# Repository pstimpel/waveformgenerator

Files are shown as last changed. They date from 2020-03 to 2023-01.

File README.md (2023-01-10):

# Waveform Generator

Video on Youtube (https://www.youtube.com/watch?v=MJ1rr9S12Lc)

Click to play video

First of all, the credit for creating the basic circuit goes to Scullcom Hobby Electronics Youtube channel, who is inactive meanwhile - sadly.

https://www.youtube.com/channel/UCDqryeq1kMDSEQwltWqASrA

Project page at Thingiverse: https://www.thingiverse.com/thing:4243526

Project page at Prusaprinters: https://www.prusaprinters.org/prints/27172-xr2206-waveform-generator

## Why?

Someone said: when starting the hobby electronics, you will need to build 2 things, a power supply and a waveform generator.

## Again, why?

I was keen to dive into electronics again, after 20 years of ignoring this hobby. To get some practice again, I thought building such a generator would be fun. It was fun. 

## What did you change on the original circuit?

Based on Scullcoms circuit I started creating an Arduino controlled waveform gegenerator. My goal was to control as much as possible by the Arduino. So I removed the following parts from the original circuit:

* switch for changing from sine to triangle wave
* switch for changing from sine/triangle to square wave
* switch for enabling pulse width modulation
* switch for changing the frequency range

I replaced them with a relay and some opto isolators.

## Was there any challenge?

Uh, plenty of challenges. 

Figuring out how to replace mechanical switches by opto isolators and relay was kind of a long way for me. First of, I tried to do it by simple transistors, and failed. So opto isolators were the next try, and I was able to replace 3 of 4 switches by these ICs. One left. So I tried a micro relay, and this worked out great.

Another issue I had was to balance out the whole circuit, so I would be able to select halfway decent frequency ranges. Finally, a big enough coarse frequency potentiometer combined with a trim poti did the trick. My goal was to have kind of smooth waveforms, not to hunt Megahertzes for the marketing paper. 

I built the whole circuit at least 4 times on breadboards. And what to tell: those breadboards can be a pain in the ass, at least the cheapos. 

## What can you expect?

You will get a waveform generator able to generate sine, triangle and square waves. The frequency range is from about 1 Hz up to 100 kHz, split into 5 ranges you can switch between (1-10, 10-100, 100 to 1,000, 1,000 to 10,000 and 10,000 to 100,000 Hz, roughly). You can adjust the frequency within these ranges by two potis. The amplitude is about +5 to -5 V (adjustable) at the 50 Ohms output, and from 0 to 5V at the TTL output. There is a basic Pulse width modulation available as well. You can adjust the pulse width. By combining sine or triangle waves and PWM you recieve kind of a ramp modulation. The waveform is quite solid, but with 100kHz you will see some distortion and spikes. It seems this is kind of a typical behavior of the XR2206 chipset. There is a frequency counter used to display the set frequency. However, this is kind of an estimation, especially in very low Hz ranges.

## What you will find in this repository

### Folder enclosure

This folder contains the stl files to 3D print the enclosure. I was using PLA and my Prusa I3 Mk3 printer. On top, there are 2 PDFs containing labels. You could just print them, cut them out of the sheet of paper, use an exacto knife to cut the holes, and mount it to the front of your enclosure

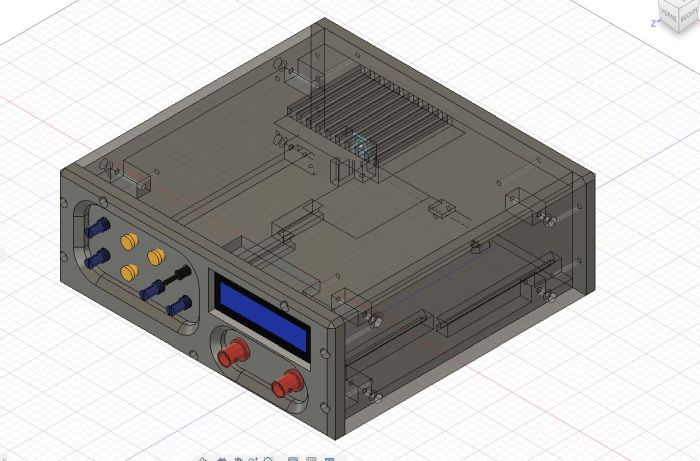
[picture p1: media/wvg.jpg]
Enclosure in Fusion 360


### Folder circuits

There are 2 circuits. One keeps all the control stuff and the Arduino, and the other creates the waveform and gets controlled by the control board. There are gerber files, the KICAD board file, and PDFs with the circuit scheme itself. In each subfolder you wil find a list of parts. 

## What to buy (BOM)

Beside the stuff from the parts lists in the circuit folders, you will need

* potentiometer 10k linear, 6mm axle (gain control)
* potentiometer 1M linear, 6mm axle (frequency control, coarse)
* potentiometer 10k linear, 6mm axle (frequency control, fine)
* potentiometer 1ook linear, 6mm axle (PWM control)
* 3 push buttons, closing type, like in https://www.amazon.de/gp/product/B07MY2WVQ3
* 1 switch, like in https://www.amazon.de/gp/product/B07MY2WVQ3
* 1 smaller heatsink for TO220, LM7812
* 1 midsze heatsink for TO220, LM7805
* 15 V power supply with 5.5x2.1 connector
* matching 5.5x2.1 socket for your power supply
* 25 cylinderhead screws, M3x12
* 16x2 I2C LED for Arduino
* 2 BNC sockets
* wires
* Pinheaders 2.54mm
* matching IC sockets if you dislike soldering the ICs to the PCB directly (2x 8pin, 1x 14pin, 3x 16pin)
* 3 screw terminals, 2 poles, 5mm 
* dupont style wires or similar to connect to pinheaders

## Howto

### Fast lane

Order PCBs and parts, solder all the stuff together, patch the Arduino using the sketch provided, 3d Print the enclosure, put PCBs inside enclosure, mount LCD, potis and switches to the front, solder dupont style wires to them, connect with the PCBs, mount BNC sockets to the front, use some cable to connect them to the PCB, insert 5.5x2.1 soocket in its pocket, lock it using the lock, connect it to the PCB. Lock the PCBs using the pcblock, secure it using one of the screws. Close the enclosure. Connect power, switch the device on, and have fun.

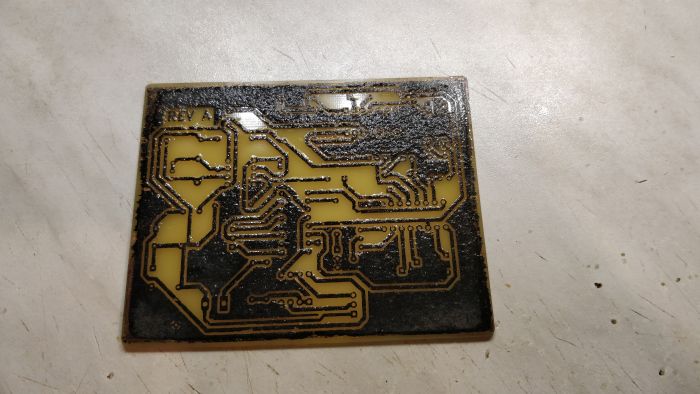
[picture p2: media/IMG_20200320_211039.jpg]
Etching one of the PCBs


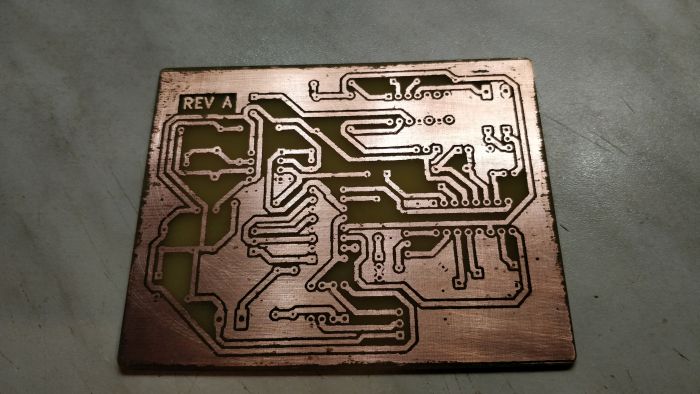
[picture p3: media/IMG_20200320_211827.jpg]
Final PCB


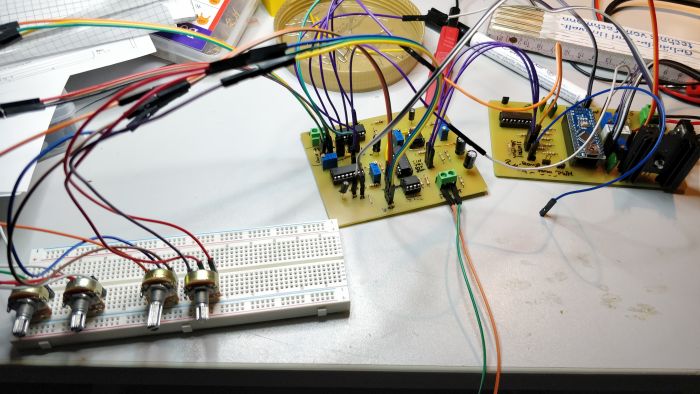
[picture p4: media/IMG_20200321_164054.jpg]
Does it work?


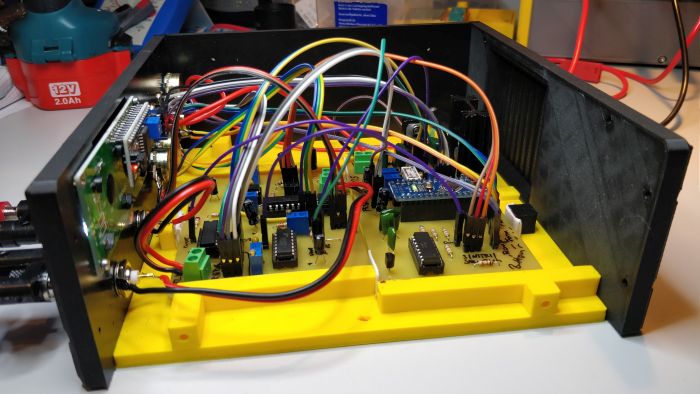
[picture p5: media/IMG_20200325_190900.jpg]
Put the stuff into the enclosure


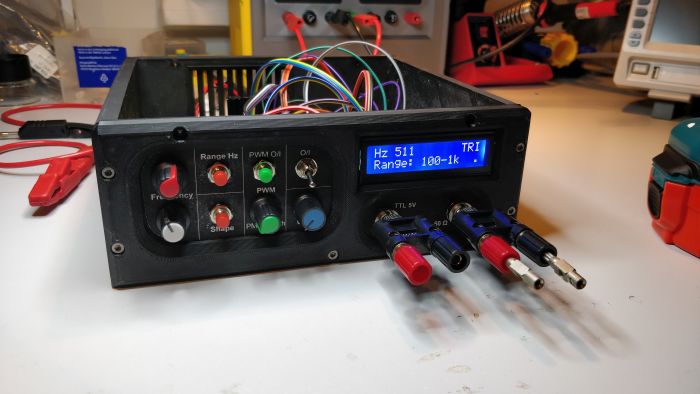
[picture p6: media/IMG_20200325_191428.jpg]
Still working?


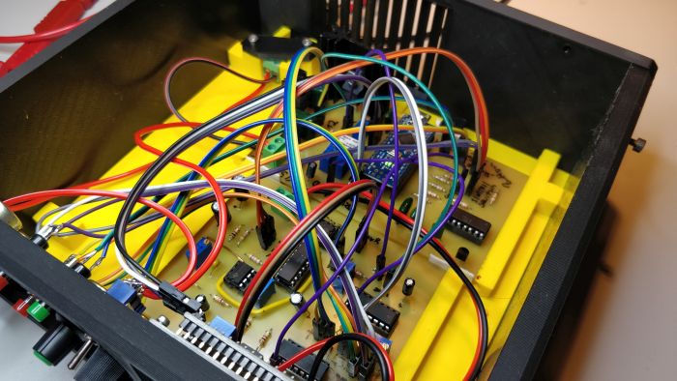
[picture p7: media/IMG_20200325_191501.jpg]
Some mayhem


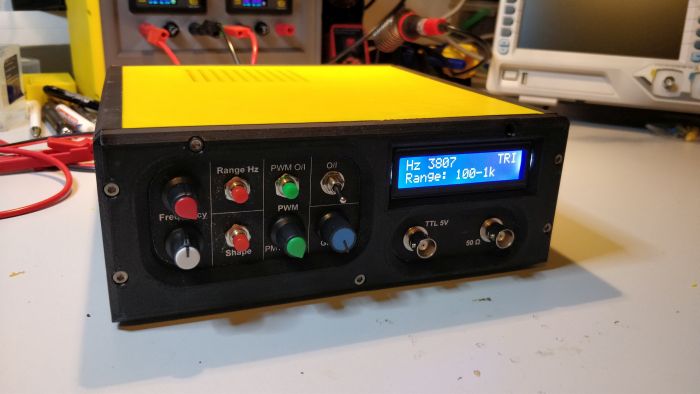
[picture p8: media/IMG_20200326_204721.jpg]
Done!


## Remarks, hints

### Arduino

To run the display you will need to add library LiquidCrystal_I2C by Frank de Brabander.

To have frequence counting, you will need to add library FreqCounter by Martin Nawrath.

### Breadboarding

I highly recommend testing the circuit on a breadboard before you go for the soldering stuff. You will learn much more that way than by just following this rough guide. 

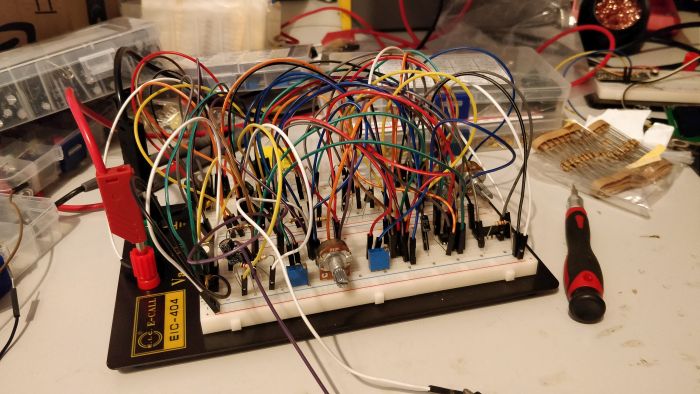
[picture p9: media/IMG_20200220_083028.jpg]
Half of the circuit


### Pricing vs functionality vs fun

If you look for a decent waveform generator delivering Megahertz samples, buy one. 

If you look for the cheapest of all solutions, by such a chinese XR2206 kit for less than 10 USD.

If you want to enjoy DIY, start buying parts and follow the guide I provided. Good luck, wish you well.

### Credits

'rine 77' https://github.com/rine77 contributed updated circuit data, compatible with Kicad6

## CORONA

This project was finished during the spare time provided by Corona. If someone reads this in the future, I really hope Corona is no issue anymore. Until then: stay safe, wash your hands, and take care of your family.

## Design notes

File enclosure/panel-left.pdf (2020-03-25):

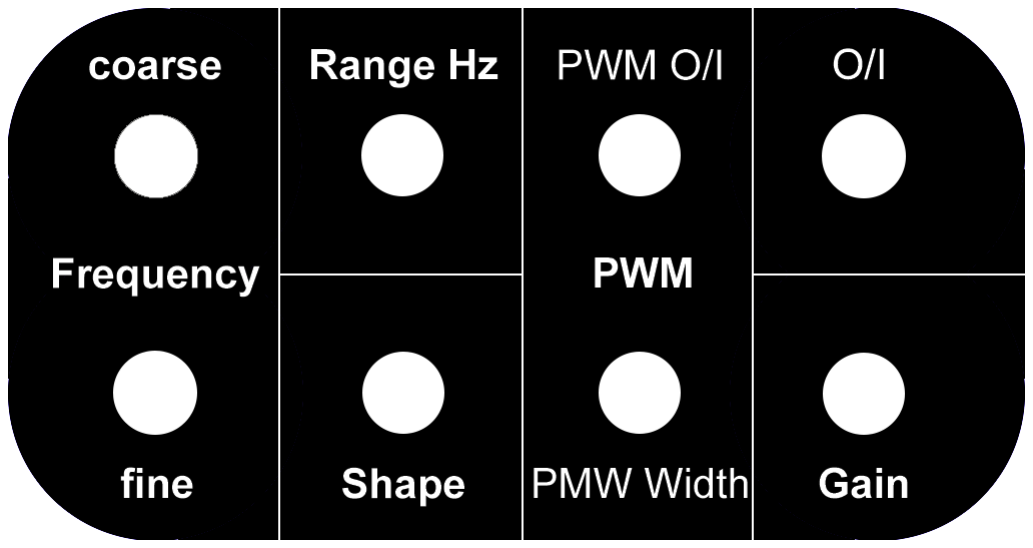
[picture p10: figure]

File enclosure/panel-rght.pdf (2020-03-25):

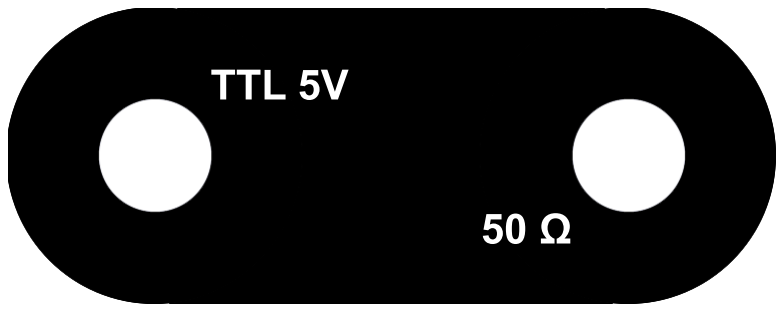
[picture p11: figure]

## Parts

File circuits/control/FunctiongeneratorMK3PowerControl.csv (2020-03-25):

Ref | Value | Part | Footprint | Description | Vendor
A1 | Arduino_Nano_v3.x | MCU_Module:Arduino_Nano_v3.x | Module:Arduino_Nano | Arduino Nano v3.x
C1 | 100nF | Device:C | Capacitor_THT:C_Disc_D8.0mm_W5.0mm_P7.50mm | Unpolarized capacitor
C2 | 1uF | Device:CP | Capacitor_THT:CP_Radial_D8.0mm_P5.00mm | Polarized capacitor
C3 | 330nF | Device:C | Capacitor_THT:C_Disc_D8.0mm_W5.0mm_P7.50mm | Unpolarized capacitor
C4 | 330nF | Device:C | Capacitor_THT:C_Disc_D8.0mm_W5.0mm_P7.50mm | Unpolarized capacitor
C5 | 100nF | Device:C | Capacitor_THT:C_Disc_D8.0mm_W5.0mm_P7.50mm | Unpolarized capacitor
C6 | 100nF | Device:C | Capacitor_THT:C_Disc_D8.0mm_W5.0mm_P7.50mm | Unpolarized capacitor
C7 | 10uF | Device:CP | Capacitor_THT:CP_Radial_D8.0mm_P5.00mm | Polarized capacitor
C8 | 1nF | Device:C | Capacitor_THT:C_Disc_D8.0mm_W5.0mm_P7.50mm | Unpolarized capacitor
C9 | 10nF | Device:C | Capacitor_THT:C_Disc_D8.0mm_W5.0mm_P7.50mm | Unpolarized capacitor
D1 | 1N4007 | Diode:1N4007 | Diode_THT:D_DO-41_SOD81_P10.16mm_Horizontal | 1000V 1A General Purpose Rectifier Diode, DO-41
D2 | 1N4007 | Diode:1N4007 | Diode_THT:D_DO-41_SOD81_P10.16mm_Horizontal | 1000V 1A General Purpose Rectifier Diode, DO-41
J1 | SIN-TRI-SQU-PWM | Connector:Conn_01x03_Male | Connector_PinHeader_2.54mm:PinHeader_1x03_P2.54mm_Vertical | Generic connector, single row, 01x03, script generated (kicad-library-utils/schlib/autogen/connector/)
J2 | BTN Range | Connector:Conn_01x02_Male | Connector_PinHeader_2.54mm:PinHeader_1x02_P2.54mm_Vertical | Generic connector, single row, 01x02, script generated (kicad-library-utils/schlib/autogen/connector/)
J3 | BTN Form | Connector:Conn_01x02_Male | Connector_PinHeader_2.54mm:PinHeader_1x02_P2.54mm_Vertical | Generic connector, single row, 01x02, script generated (kicad-library-utils/schlib/autogen/connector/)
J4 | BTN PWM | Connector:Conn_01x02_Male | Connector_PinHeader_2.54mm:PinHeader_1x02_P2.54mm_Vertical | Generic connector, single row, 01x02, script generated (kicad-library-utils/schlib/autogen/connector/)
J5 | FreqRange | Connector:Conn_01x02_Male | Connector_PinHeader_2.54mm:PinHeader_1x02_P2.54mm_Vertical | Generic connector, single row, 01x02, script generated (kicad-library-utils/schlib/autogen/connector/)
J6 | WaveA1 | Connector:Conn_01x01_Male | Connector_PinHeader_2.54mm:PinHeader_1x01_P2.54mm_Vertical | Generic connector, single row, 01x01, script generated (kicad-library-utils/schlib/autogen/connector/)
J7 | FreqCount | Connector:Conn_01x01_Male | Connector_PinHeader_2.54mm:PinHeader_1x01_P2.54mm_Vertical | Generic connector, single row, 01x01, script generated (kicad-library-utils/schlib/autogen/connector/)
J8 | Display | Connector:Conn_01x04_Male | Connector_PinHeader_2.54mm:PinHeader_1x04_P2.54mm_Vertical | Generic connector, single row, 01x04, script generated (kicad-library-utils/schlib/autogen/connector/)
J9 | 14V | Connector:Screw_Terminal_01x02 | TerminalBlock:TerminalBlock_Altech_AK300-2_P5.00mm | Generic screw terminal, single row, 01x02, script generated (kicad-library-utils/schlib/autogen/connector/)
J10 | 12V GND 5V | Connector:Conn_01x03_Male | Connector_PinHeader_2.54mm:PinHeader_1x03_P2.54mm_Vertical | Generic connector, single row, 01x03, script generated (kicad-library-utils/schlib/autogen/connector/)
J11 | WaveA2 | Connector:Conn_01x01_Male | Connector_PinHeader_2.54mm:PinHeader_1x01_P2.54mm_Vertical | Generic connector, single row, 01x01, script generated (kicad-library-utils/schlib/autogen/connector/)
J12 | MO | Connector:Conn_01x01_Male | Connector_PinHeader_2.54mm:PinHeader_1x01_P2.54mm_Vertical | Generic connector, single row, 01x01, script generated (kicad-library-utils/schlib/autogen/connector/)
K1 | G6S-2 | Relay:G6S-2 | Relay_THT:Relay_DPDT_Omron_G6S-2 | Compact, Industry-Standard 2-pole relay, designed to switch 2A Signal Loads, Single-side Stable
Q1 | BC337 | Transistor_BJT:BC337 | Package_TO_SOT_THT:TO-220-3_Vertical | 0.8A Ic, 45V Vce, NPN Transistor, TO-92
R1 | 390R | Device:R | Resistor_THT:R_Axial_DIN0207_L6.3mm_D2.5mm_P10.16mm_Horizontal | Resistor
R2 | 390R | Device:R | Resistor_THT:R_Axial_DIN0207_L6.3mm_D2.5mm_P10.16mm_Horizontal | Resistor
R3 | 390 | Device:R | Resistor_THT:R_Axial_DIN0207_L6.3mm_D2.5mm_P10.16mm_Horizontal | Resistor
R4 | 270 | Device:R | Resistor_THT:R_Axial_DIN0207_L6.3mm_D2.5mm_P10.16mm_Horizontal | Resistor
R5 | 390 | Device:R | Resistor_THT:R_Axial_DIN0207_L6.3mm_D2.5mm_P10.16mm_Horizontal | Resistor
R6 | 10k | Device:R | Resistor_THT:R_Axial_DIN0207_L6.3mm_D2.5mm_P10.16mm_Horizontal | Resistor
R7 | 10k | Device:R | Resistor_THT:R_Axial_DIN0207_L6.3mm_D2.5mm_P10.16mm_Horizontal | Resistor
R8 | 10k | Device:R | Resistor_THT:R_Axial_DIN0207_L6.3mm_D2.5mm_P10.16mm_Horizontal | Resistor
R9 | 390R | Device:R | Resistor_THT:R_Axial_DIN0207_L6.3mm_D2.5mm_P10.16mm_Horizontal | Resistor
R10 | 390R | Device:R | Resistor_THT:R_Axial_DIN0207_L6.3mm_D2.5mm_P10.16mm_Horizontal | Resistor
RV1 | 500 | Device:R_POT_TRIM | Potentiometer_THT:Potentiometer_Bourns_3266Y_Vertical | Trim-potentiometer
RV2 | 50k | Device:R_POT_TRIM | Potentiometer_THT:Potentiometer_Bourns_3266Y_Vertical | Trim-potentiometer
RV3 | 50k | Device:R_POT_TRIM | Potentiometer_THT:Potentiometer_Bourns_3266Y_Vertical | Trim-potentiometer
U1 | LTV-847 | Isolator:LTV-847 | Package_DIP:DIP-16_W7.62mm | Quad DC Optocoupler, Vce 35V, CTR 50%, DIP-16
U2 | LM7812_TO220 | Regulator_Linear:LM7812_TO220 | Package_TO_SOT_THT:TO-220-3_Vertical | Positive 1A 35V Linear Regulator, Fixed Output 12V, TO-220
U3 | LM7805_TO220 | Regulator_Linear:LM7805_TO220 | Package_TO_SOT_THT:TO-220-3_Vertical | Positive 1A 35V Linear Regulator, Fixed Output 5V, TO-220

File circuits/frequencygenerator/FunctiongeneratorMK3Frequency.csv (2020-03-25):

Ref | Value | Part | Footprint | Description | Vendor
C1 | 100pF | Device:C | Capacitor_THT:C_Disc_D9.0mm_W5.0mm_P7.50mm | Unpolarized capacitor
C2 | 10uF | Device:CP | Capacitor_THT:CP_Radial_D8.0mm_P5.00mm | Polarized capacitor
C3 | 10u | Device:CP | Capacitor_THT:CP_Radial_D8.0mm_P5.00mm | Polarized capacitor
C4 | 1u | Device:CP | Capacitor_THT:CP_Radial_D8.0mm_P5.00mm | Polarized capacitor
C6 | 220uF | Device:CP | Capacitor_THT:CP_Radial_D8.0mm_P5.00mm | Polarized capacitor
C7 | 220uF | Device:CP | Capacitor_THT:CP_Radial_D8.0mm_P5.00mm | Polarized capacitor
C8 | 100pF | Device:C | Capacitor_THT:C_Disc_D9.0mm_W5.0mm_P7.50mm | Unpolarized capacitor
J1 | FreqRange | Connector:Conn_01x02_Male | Connector_PinHeader_2.54mm:PinHeader_1x02_P2.54mm_Vertical | Generic connector, single row, 01x02, script generated (kicad-library-utils/schlib/autogen/connector/)
J2 | WaveA1 | Connector:Conn_01x01_Male | Connector_PinHeader_2.54mm:PinHeader_1x01_P2.54mm_Vertical | Generic connector, single row, 01x01, script generated (kicad-library-utils/schlib/autogen/connector/)
J3 | 12V-GND-5V | Connector:Conn_01x03_Male | Connector_PinHeader_2.54mm:PinHeader_1x03_P2.54mm_Vertical | Generic connector, single row, 01x03, script generated (kicad-library-utils/schlib/autogen/connector/)
J4 | FreqCounterD5 | Connector:Conn_01x01_Male | Connector_PinHeader_2.54mm:PinHeader_1x01_P2.54mm_Vertical | Generic connector, single row, 01x01, script generated (kicad-library-utils/schlib/autogen/connector/)
J5 | TTL OUT | Connector:Screw_Terminal_01x02 | TerminalBlock:TerminalBlock_Altech_AK300-2_P5.00mm | Generic screw terminal, single row, 01x02, script generated (kicad-library-utils/schlib/autogen/connector/)
J6 | SIN-TRI-SQU-PWM | Connector:Conn_01x03_Male | Connector_PinHeader_2.54mm:PinHeader_1x03_P2.54mm_Vertical | Generic connector, single row, 01x03, script generated (kicad-library-utils/schlib/autogen/connector/)
J7 | PulseWidth 100k | Connector:Conn_01x03_Male | Connector_PinHeader_2.54mm:PinHeader_1x03_P2.54mm_Vertical | Generic connector, single row, 01x03, script generated (kicad-library-utils/schlib/autogen/connector/)
J8 | FreqCoarse 1M | Connector:Conn_01x03_Male | Connector_PinHeader_2.54mm:PinHeader_1x03_P2.54mm_Vertical | Generic connector, single row, 01x03, script generated (kicad-library-utils/schlib/autogen/connector/)
J9 | FreqFine 10k | Connector:Conn_01x03_Male | Connector_PinHeader_2.54mm:PinHeader_1x03_P2.54mm_Vertical | Generic connector, single row, 01x03, script generated (kicad-library-utils/schlib/autogen/connector/)
J10 | 50 Ohm OUT | Connector:Screw_Terminal_01x02 | TerminalBlock:TerminalBlock_Altech_AK300-2_P5.00mm | Generic screw terminal, single row, 01x02, script generated (kicad-library-utils/schlib/autogen/connector/)
J11 | OUT Gain 10k | Connector:Conn_01x03_Male | Connector_PinHeader_2.54mm:PinHeader_1x03_P2.54mm_Vertical | Generic connector, single row, 01x03, script generated (kicad-library-utils/schlib/autogen/connector/)
J12 | WaveA2 | Connector:Conn_01x01_Male | Connector_PinHeader_2.54mm:PinHeader_1x01_P2.54mm_Vertical | Generic connector, single row, 01x01, script generated (kicad-library-utils/schlib/autogen/connector/)
J13 | MO | Connector:Conn_01x01_Male | Connector_PinHeader_2.54mm:PinHeader_1x01_P2.54mm_Vertical | Generic connector, single row, 01x01, script generated (kicad-library-utils/schlib/autogen/connector/)
R2 | 1k | Device:R | Resistor_THT:R_Axial_DIN0207_L6.3mm_D2.5mm_P10.16mm_Horizontal | Resistor
R5 | 1k | Device:R | Resistor_THT:R_Axial_DIN0207_L6.3mm_D2.5mm_P10.16mm_Horizontal | Resistor
R6 | 1k | Device:R | Resistor_THT:R_Axial_DIN0207_L6.3mm_D2.5mm_P10.16mm_Horizontal | Resistor
R7 | 10k | Device:R | Resistor_THT:R_Axial_DIN0207_L6.3mm_D2.5mm_P10.16mm_Horizontal | Resistor
R8 | 1k | Device:R | Resistor_THT:R_Axial_DIN0207_L6.3mm_D2.5mm_P10.16mm_Horizontal | Resistor
R9 | 2k2 | Device:R | Resistor_THT:R_Axial_DIN0207_L6.3mm_D2.5mm_P10.16mm_Horizontal | Resistor
R11 | 100 | Device:R | Resistor_THT:R_Axial_DIN0207_L6.3mm_D2.5mm_P10.16mm_Horizontal | Resistor
R12 | 100 | Device:R | Resistor_THT:R_Axial_DIN0207_L6.3mm_D2.5mm_P10.16mm_Horizontal | Resistor
R13 | 1k | Device:R | Resistor_THT:R_Axial_DIN0207_L6.3mm_D2.5mm_P10.16mm_Horizontal | Resistor
R14 | 1k | Device:R | Resistor_THT:R_Axial_DIN0207_L6.3mm_D2.5mm_P10.16mm_Horizontal | Resistor
R15 | 47k | Device:R | Resistor_THT:R_Axial_DIN0207_L6.3mm_D2.5mm_P10.16mm_Horizontal | Resistor
R16 | 47k | Device:R | Resistor_THT:R_Axial_DIN0207_L6.3mm_D2.5mm_P10.16mm_Horizontal | Resistor
R17 | 10k | Device:R | Resistor_THT:R_Axial_DIN0207_L6.3mm_D2.5mm_P10.16mm_Horizontal | Resistor
R18 | 10k | Device:R | Resistor_THT:R_Axial_DIN0207_L6.3mm_D2.5mm_P10.16mm_Horizontal | Resistor
RV1 | 20k | Device:R_POT_TRIM | Potentiometer_THT:Potentiometer_Bourns_3266Y_Vertical | Trim-potentiometer
RV2 | 50k | Device:R_POT_TRIM | Potentiometer_THT:Potentiometer_Bourns_3266Y_Vertical | Trim-potentiometer
RV5 | 20k | Device:R_POT_TRIM | Potentiometer_THT:Potentiometer_Bourns_3266Y_Vertical | Trim-potentiometer
RV6 | 20k | Device:R_POT_TRIM | Potentiometer_THT:Potentiometer_Bourns_3266Y_Vertical | Trim-potentiometer
U1 | LTV-847 | Isolator:LTV-847 | Package_DIP:DIP-16_W7.62mm | Quad DC Optocoupler, Vce 35V, CTR 50%, DIP-16
U2 | XR2206CP-F | XR2206CP-F:XR2206CP-F | XR2206CP-F:DIP254P762X533-16
U3 | 74HC14 | 74xx:74HC14 | SN74HC14N:DIP254P762X508-14 | Hex inverter schmitt trigger
U4 | NE5532 | Amplifier_Operational:NE5532 | NE5532P:DIP254P762X508-8 | Dual Low-Noise Operational Amplifiers, DIP-8/SOIC-8
U5 | NE5532 | Amplifier_Operational:NE5532 | NE5532P:DIP254P762X508-8 | Dual Low-Noise Operational Amplifiers, DIP-8/SOIC-8

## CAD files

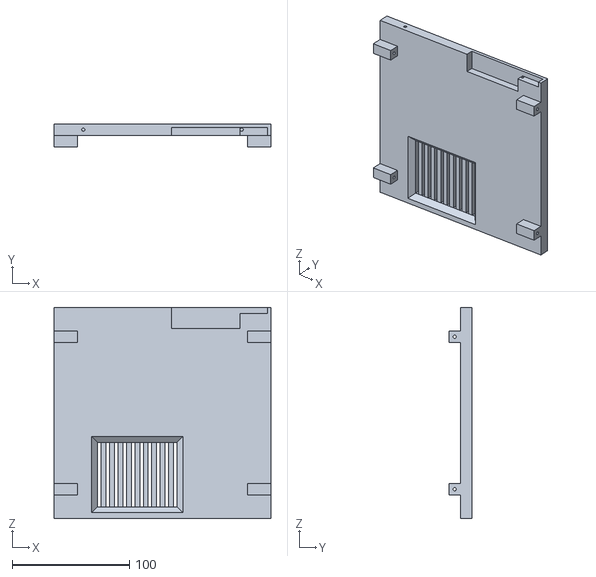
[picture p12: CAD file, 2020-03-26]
enclosure/stl/Oben.stl
185.0 x 20.0 x 180.0

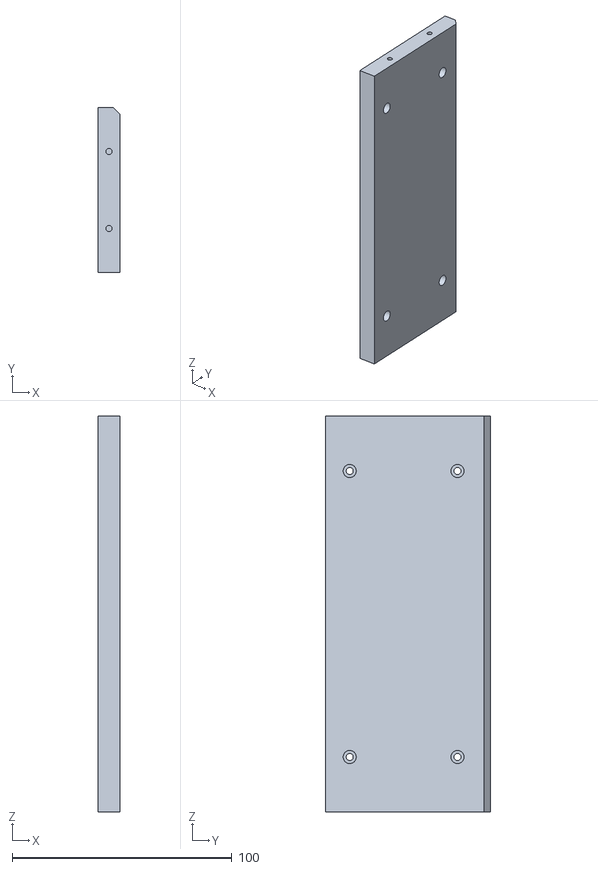
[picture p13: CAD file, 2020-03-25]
enclosure/stl/Links.stl
10.0 x 75.0 x 180.0

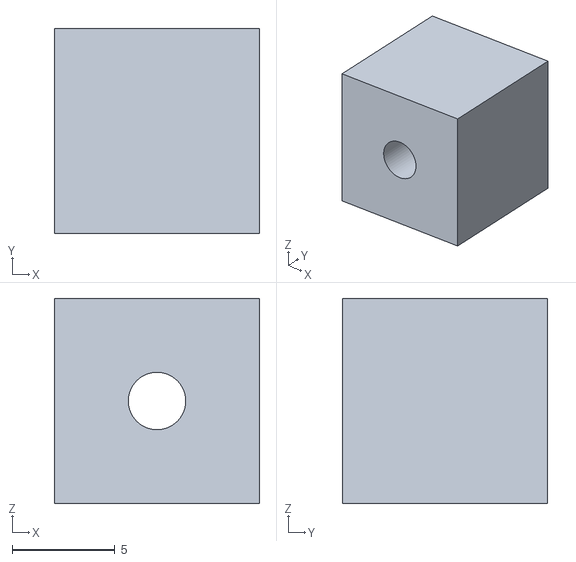
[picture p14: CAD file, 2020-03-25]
enclosure/stl/PCBLock.stl
10.0 x 10.0 x 10.0

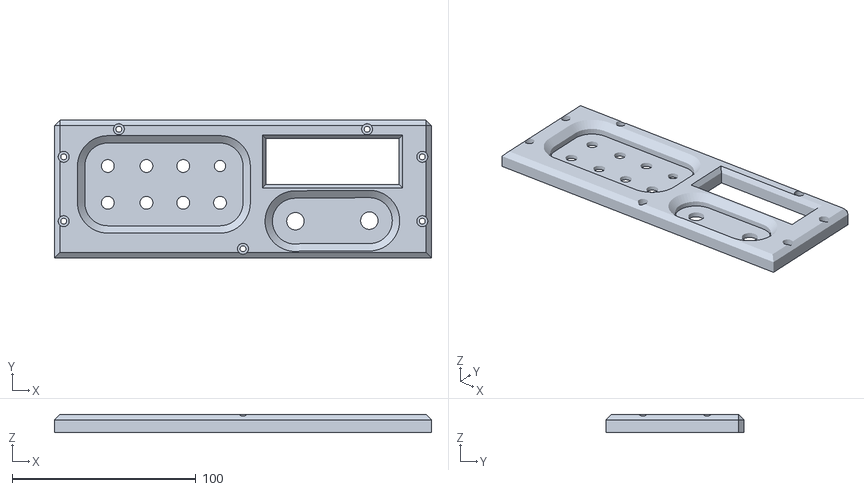
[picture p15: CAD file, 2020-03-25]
enclosure/stl/Front.stl
205.0 x 75.0 x 10.0

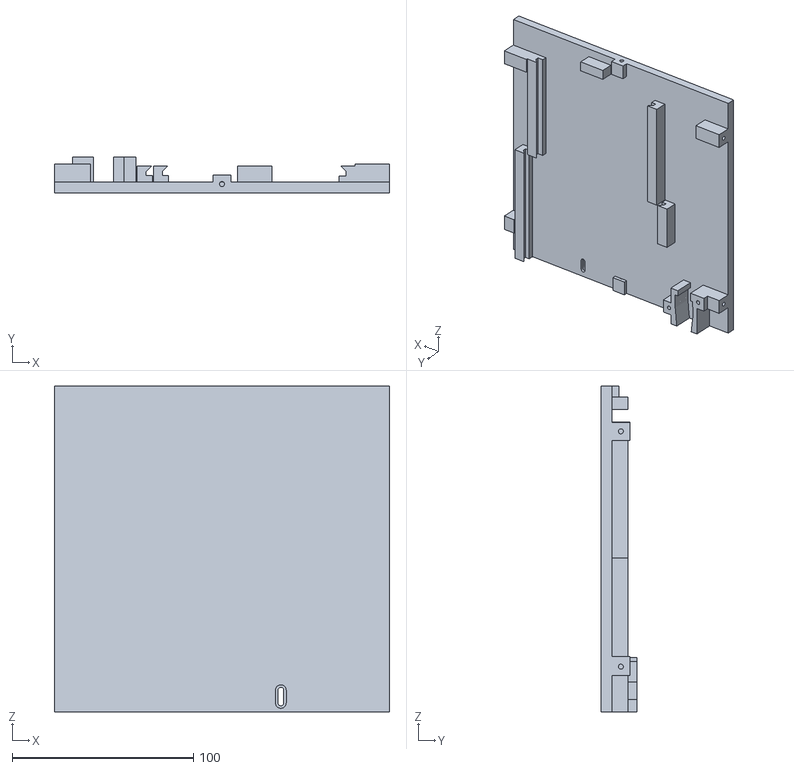
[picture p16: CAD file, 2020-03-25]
enclosure/stl/Boden.stl
185.0 x 20.0 x 180.0

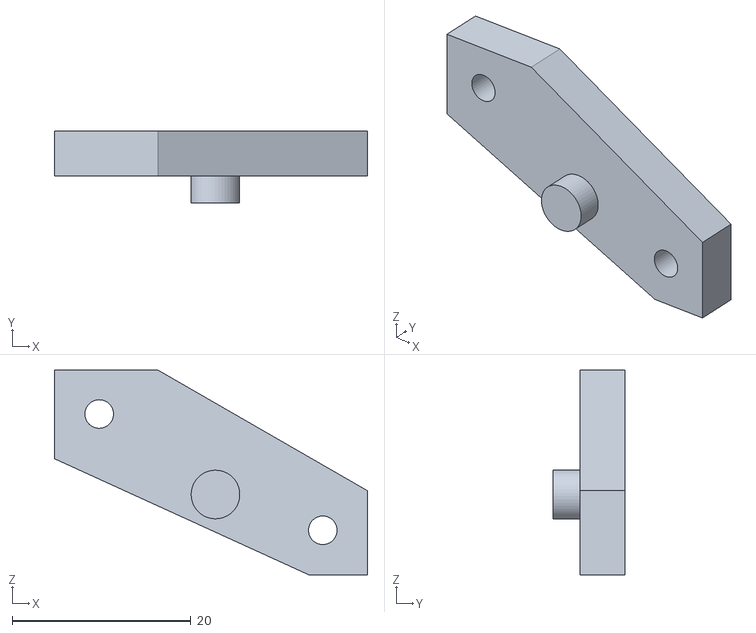
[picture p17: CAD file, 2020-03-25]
enclosure/stl/Lock.stl
35.0 x 8.00 x 22.9

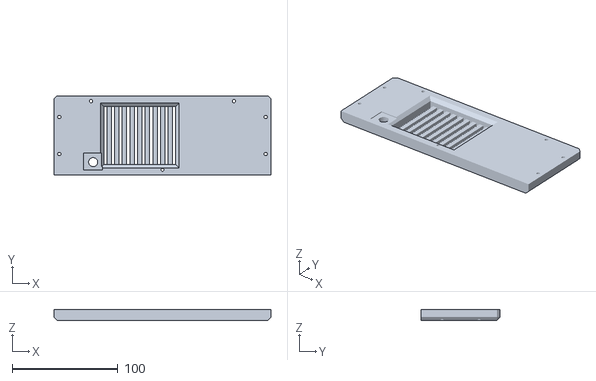
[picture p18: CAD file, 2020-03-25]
enclosure/stl/Hinten.stl
205.0 x 75.0 x 10.0

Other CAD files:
enclosure/stl/Rechts.stl

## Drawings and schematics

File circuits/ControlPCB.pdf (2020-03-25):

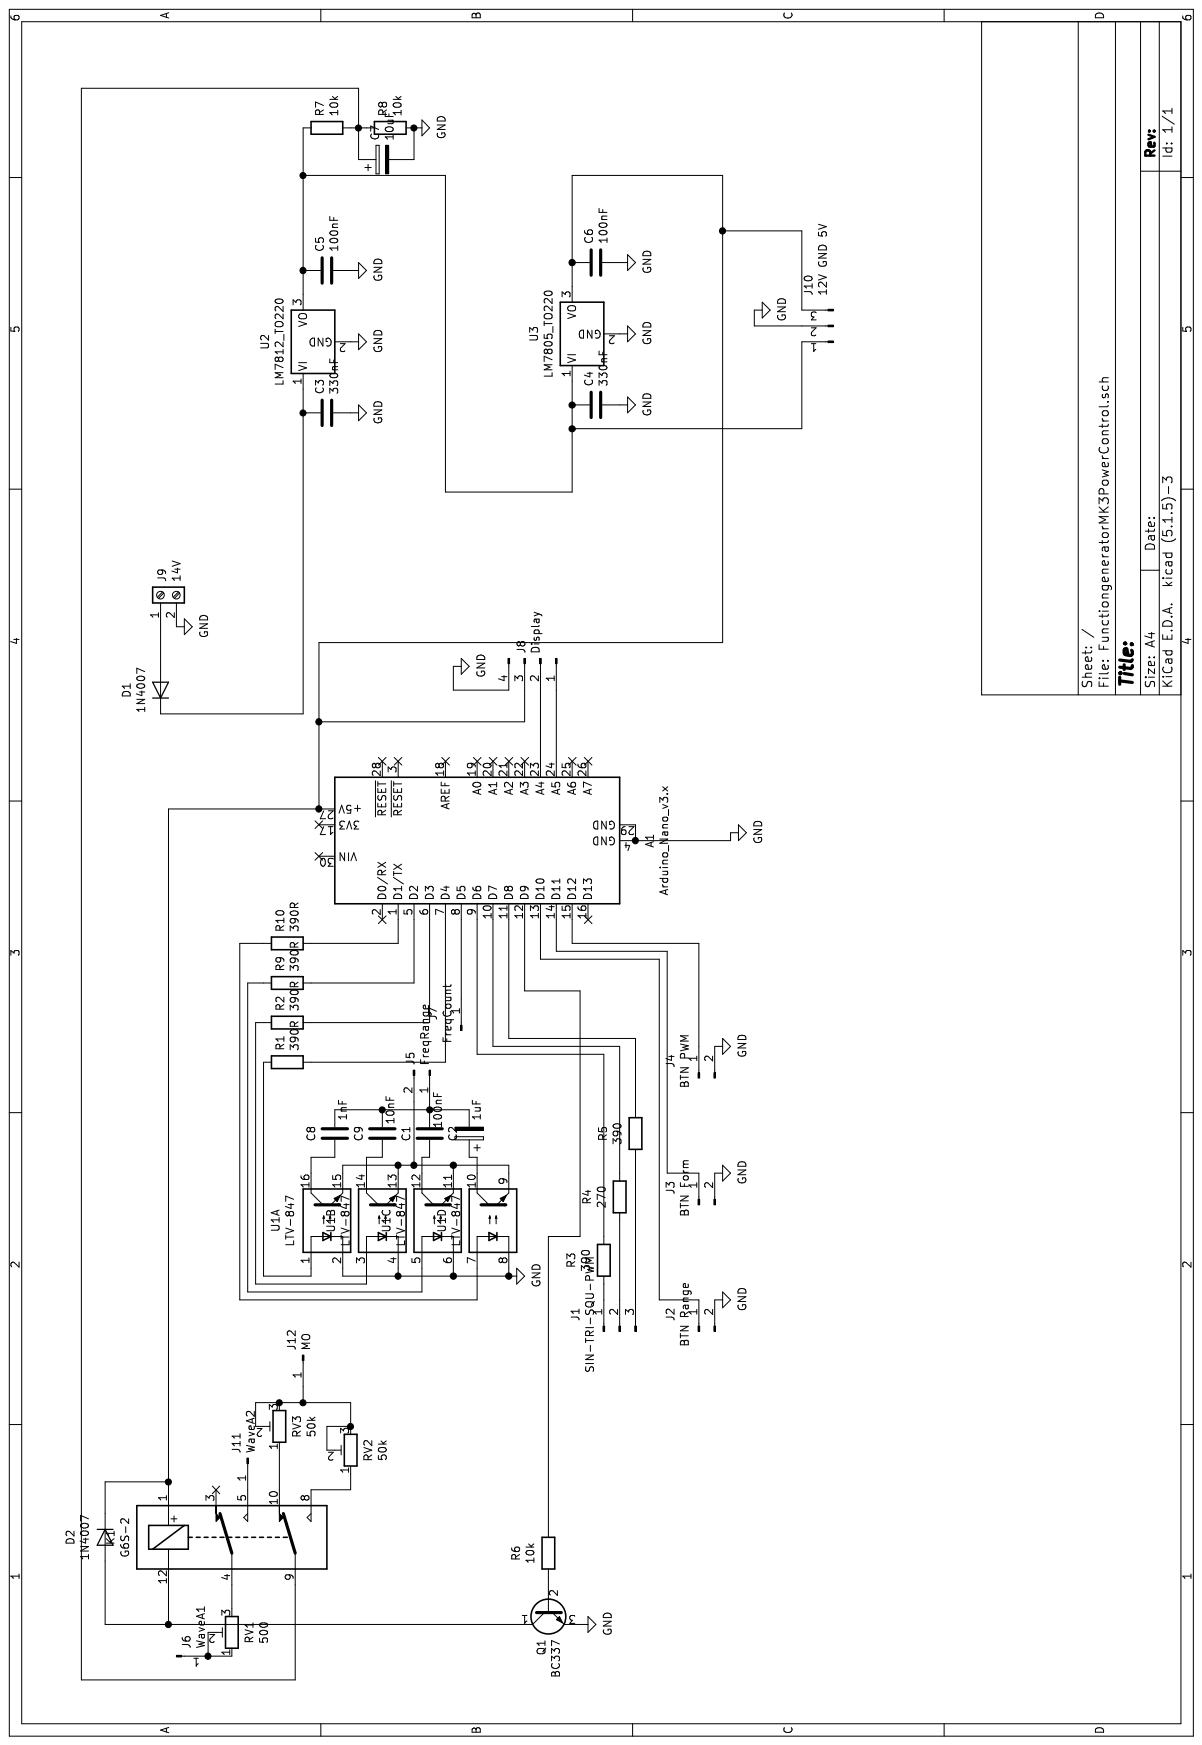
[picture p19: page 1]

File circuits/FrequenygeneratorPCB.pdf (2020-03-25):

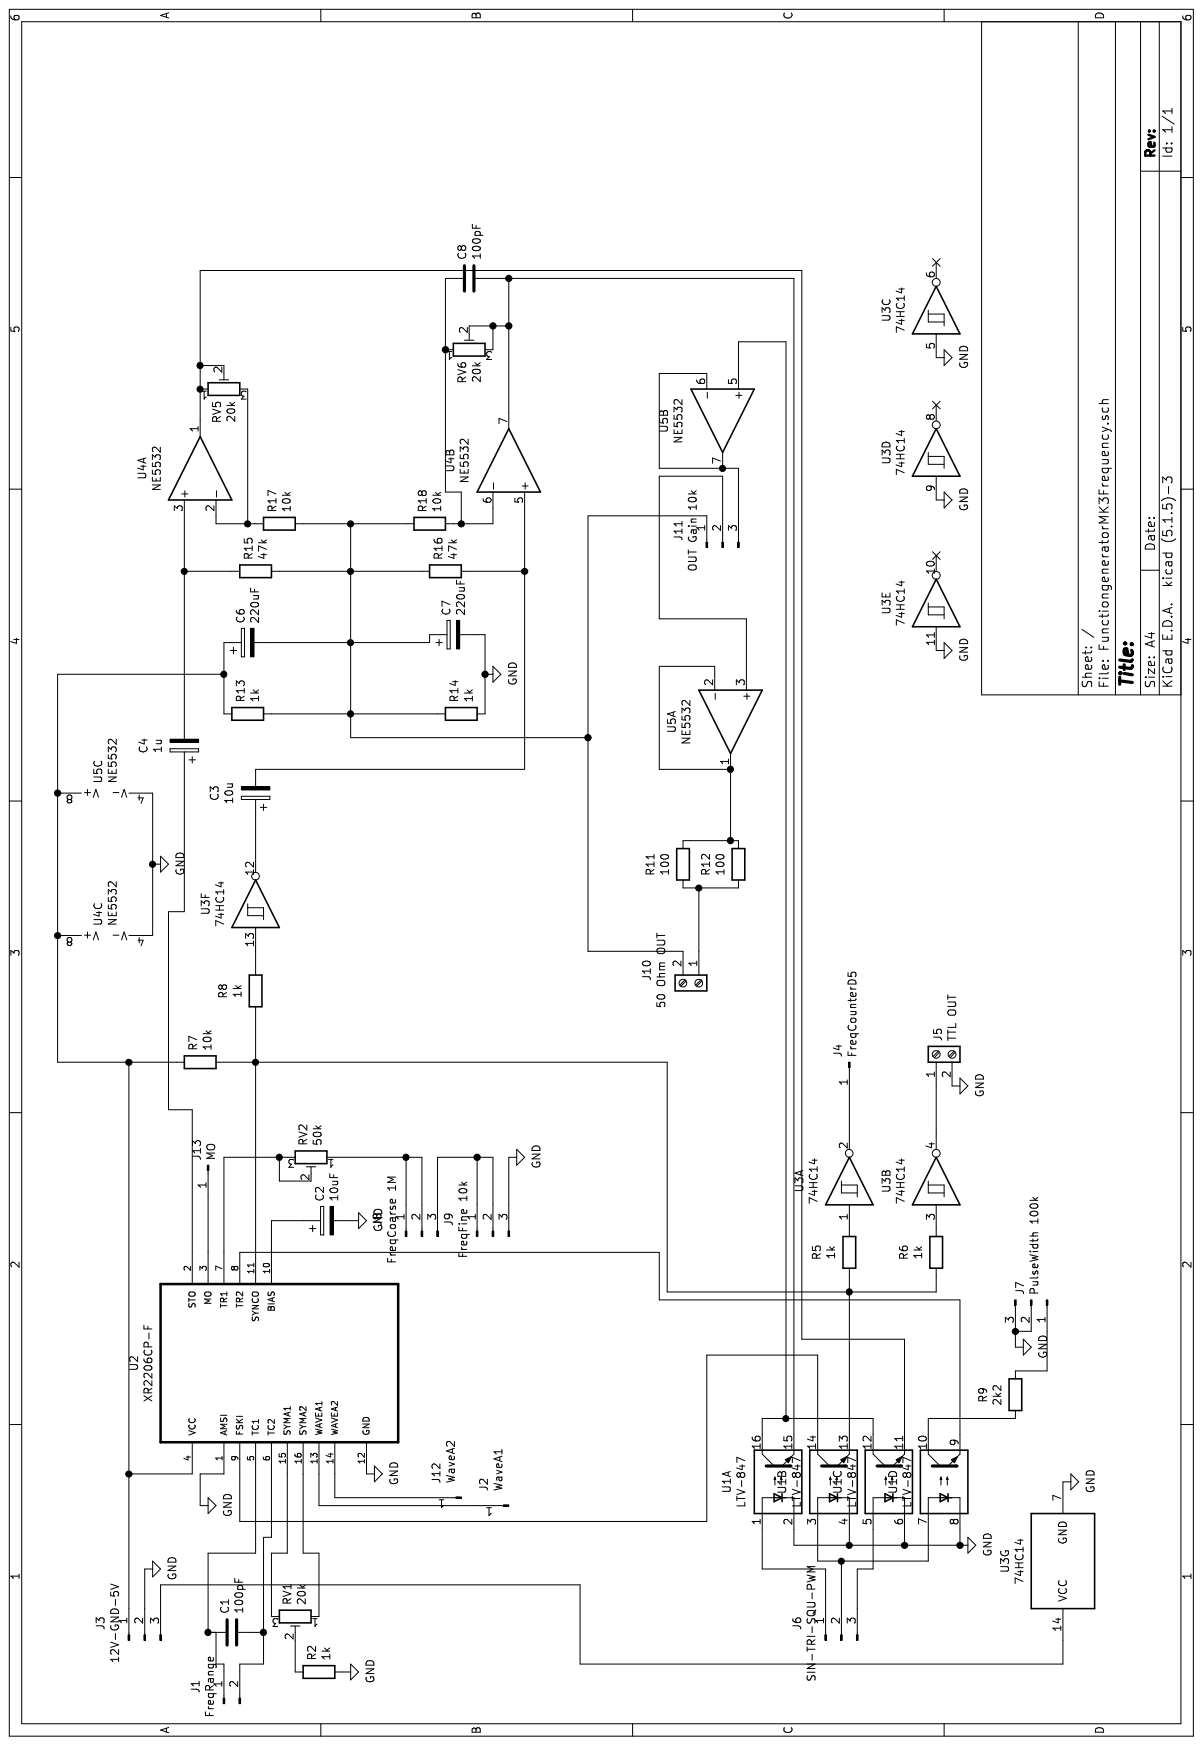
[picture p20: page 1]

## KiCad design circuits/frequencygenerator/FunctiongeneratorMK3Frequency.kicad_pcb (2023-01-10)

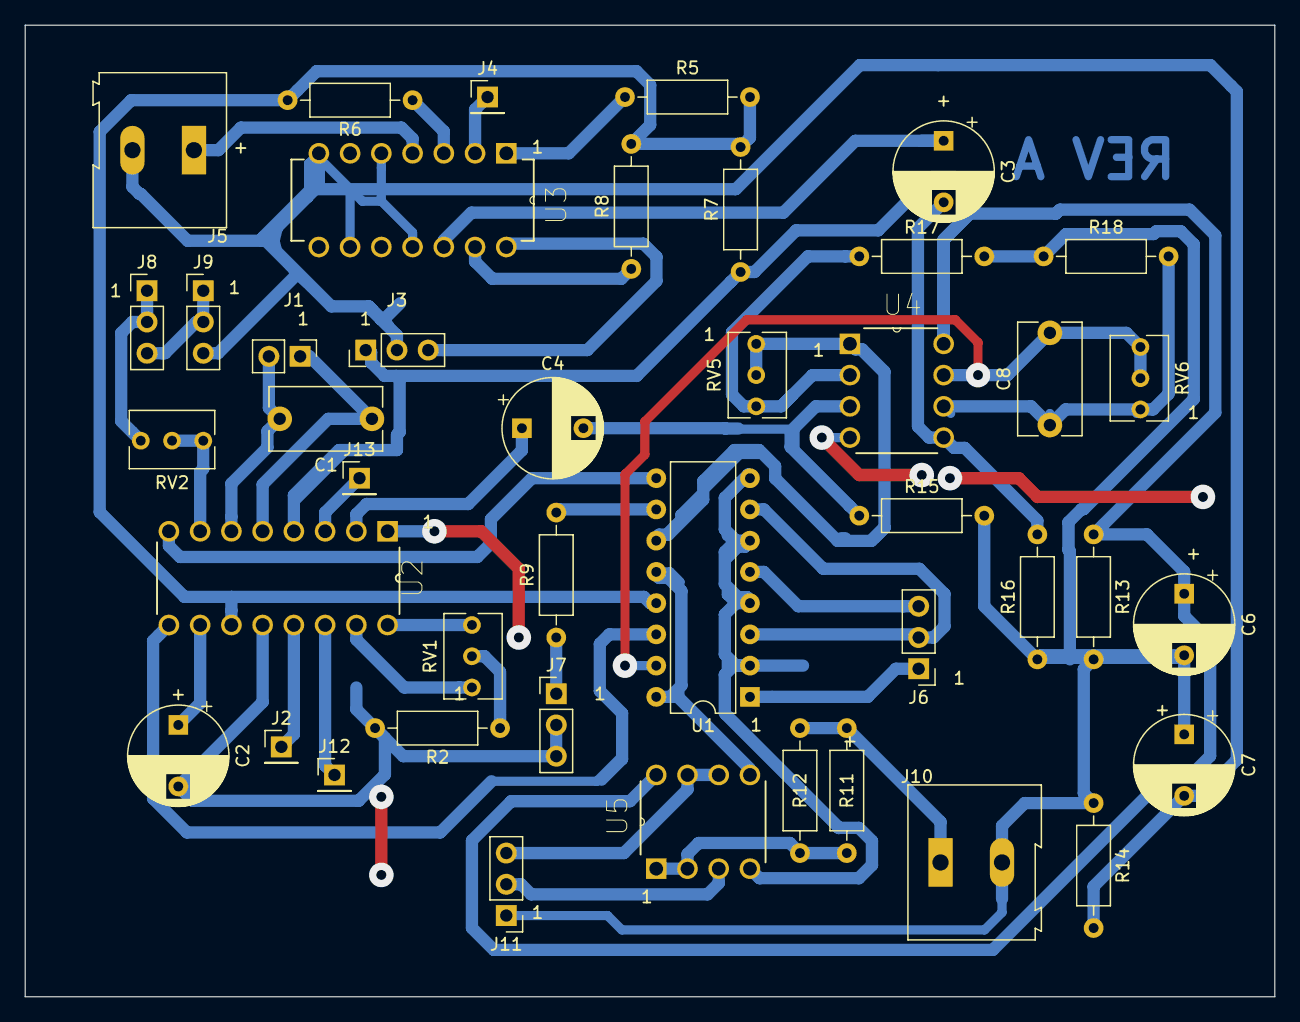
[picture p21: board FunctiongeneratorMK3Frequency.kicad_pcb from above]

Board: 2 copper layers, 101.6 x 79.0 mm, 43 parts (0 on the bottom side), 42 nets.

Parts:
C1, C8: 100pF; C_Disc_D9.0mm_W5.0mm_P7.50mm
C2: 10uF; CP_Radial_D8.0mm_P5.00mm
C3: 10u; CP_Radial_D8.0mm_P5.00mm
C4: 1u; CP_Radial_D8.0mm_P5.00mm
C6, C7: 220uF; CP_Radial_D8.0mm_P5.00mm
J1: FreqRange; PinHeader_1x02_P2.54mm_Vertical
J2: WaveA1; PinHeader_1x01_P2.54mm_Vertical
J3: 12V-GND-5V; PinHeader_1x03_P2.54mm_Vertical
J4: FreqCounterD5; PinHeader_1x01_P2.54mm_Vertical
J5: TTL OUT; TerminalBlock_Altech_AK300-2_P5.00mm
J6: SIN-TRI-SQU-PWM; PinHeader_1x03_P2.54mm_Vertical
J7: PulseWidth 100k; PinHeader_1x03_P2.54mm_Vertical
J8: FreqCoarse 1M; PinHeader_1x03_P2.54mm_Vertical
J9: FreqFine 10k; PinHeader_1x03_P2.54mm_Vertical
J10: 50 Ohm OUT; TerminalBlock_Altech_AK300-2_P5.00mm
J11: OUT Gain 10k; PinHeader_1x03_P2.54mm_Vertical
J12: WaveA2; PinHeader_1x01_P2.54mm_Vertical
J13: MO; PinHeader_1x01_P2.54mm_Vertical
R2, R5, R6, R8, R13, R14: 1k; R_Axial_DIN0207_L6.3mm_D2.5mm_P10.16mm_Horizontal
R7, R17, R18: 10k; R_Axial_DIN0207_L6.3mm_D2.5mm_P10.16mm_Horizontal
R9: 2k2; R_Axial_DIN0207_L6.3mm_D2.5mm_P10.16mm_Horizontal
R11, R12: 100; R_Axial_DIN0207_L6.3mm_D2.5mm_P10.16mm_Horizontal
R15, R16: 47k; R_Axial_DIN0207_L6.3mm_D2.5mm_P10.16mm_Horizontal
RV1, RV5, RV6: 20k; Potentiometer_Bourns_3266Y_Vertical
RV2: 50k; Potentiometer_Bourns_3266Y_Vertical
U1: LTV-847; DIP-16_W7.62mm
U2: XR2206CP-F; DIP254P762X533-16
U3: 74HC14; DIP254P762X508-14
U4, U5: NE5532; DIP254P762X508-8

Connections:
GND: C2.2, C7.2, J3.2, J5.2, J7.2, J7.3, J9.3, R2.2, R14.2, U1.2, U1.4, U1.6, U1.8, U2.1, U2.12, U3.5, U3.7, U3.9, U3.11, U4.4, U5.4
unnamed: C1.1, J1.1, U2.5
unnamed: C1.2, J1.2, U2.6
unnamed: C2.1, U2.10
unnamed: C3.1, U3.12
unnamed: C3.2, R16.2, U4.5
unnamed: C4.1, U2.2
unnamed: C4.2, R15.1, U4.3
unnamed: C6.1, J3.1, R7.1, R13.1, U2.4, U4.8, U5.8
unnamed: C6.2, C7.1, J10.2, J11.1, R13.2, R14.1, R15.2, R16.1, R17.2, R18.1
unnamed: C8.1, R18.2, RV6.1, U4.6
unnamed: C8.2, RV6.2, RV6.3, U1.15, U4.7
unnamed: J2.1, U2.13
unnamed: J3.3, U3.14
unnamed: J4.1, U3.2
unnamed: J5.1, U3.4
unnamed: J6.1, U1.1
unnamed: J6.2, U1.3, U1.7
unnamed: J6.3, U1.5
unnamed: J7.1, R9.1
unnamed: J8.1, J8.2, RV2.1
unnamed: J8.3, J9.1, J9.2
unnamed: J10.1, R11.2, R12.2
unnamed: J11.2, U5.3
unnamed: J11.3, U5.6, U5.7
unnamed: J12.1, U2.14
unnamed: J13.1, U2.3
unnamed: R2.1, RV1.2
unnamed: R5.1, U3.1
unnamed: R5.2, R6.2, R7.2, R8.2, U1.13, U2.11
unnamed: R6.1, U3.3
unnamed: R8.1, U3.13
unnamed: R9.2, U1.10
unnamed: R11.1, R12.1, U5.1, U5.2
unnamed: R17.1, RV5.3, U4.2
unnamed: RV1.1, U2.16
unnamed: RV1.3, U2.15
unnamed: RV2.2, RV2.3, U2.7
unnamed: RV5.1, RV5.2, U1.11, U4.1
unnamed: U1.9, U2.8
unnamed: U1.12, U1.16, U5.5
unnamed: U1.14, U2.9

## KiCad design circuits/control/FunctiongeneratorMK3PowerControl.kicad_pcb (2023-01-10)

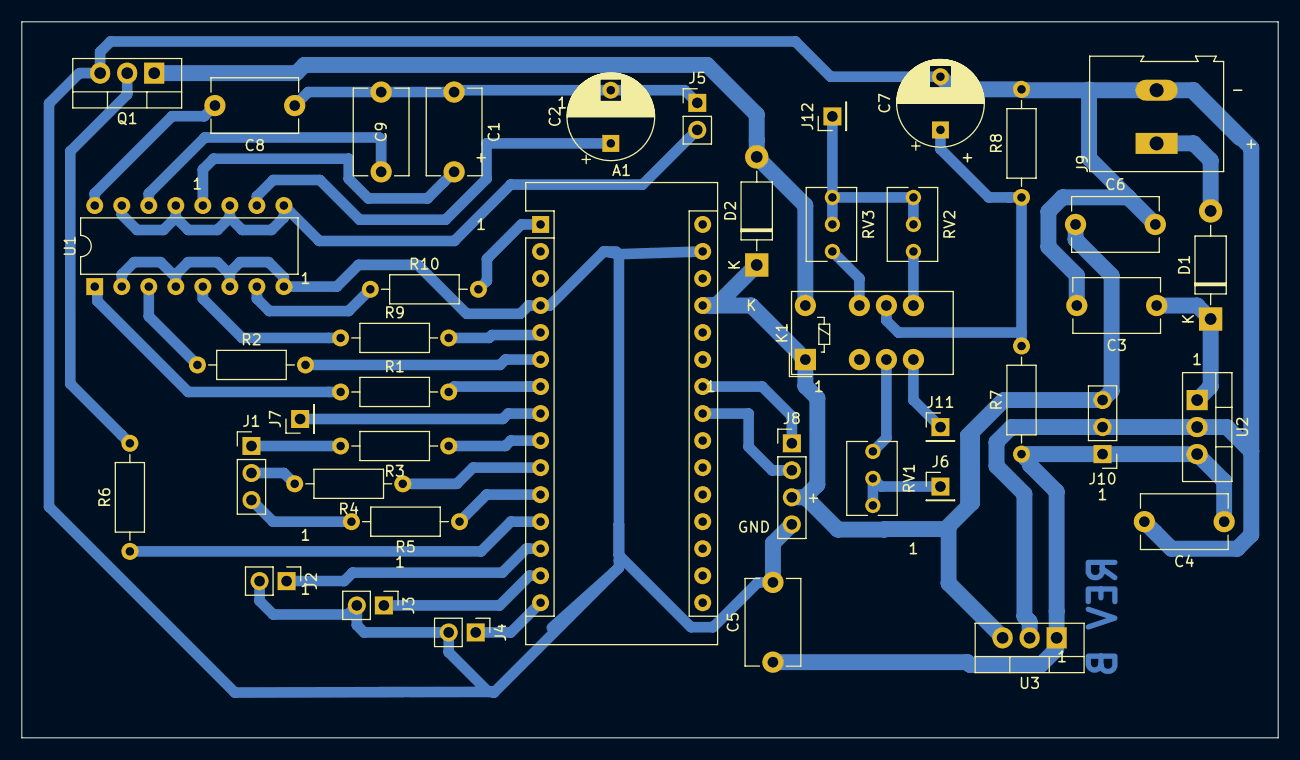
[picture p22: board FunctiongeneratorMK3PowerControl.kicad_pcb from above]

Board: 2 copper layers, 118.1 x 67.3 mm, 42 parts (0 on the bottom side), 41 nets.

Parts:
A1: Arduino_Nano_v3.x; Arduino_Nano
C1, C5, C6: 100nF; C_Disc_D8.0mm_W5.0mm_P7.50mm
C2: 1uF; CP_Radial_D8.0mm_P5.00mm
C3, C4: 330nF; C_Disc_D8.0mm_W5.0mm_P7.50mm
C7: 10uF; CP_Radial_D8.0mm_P5.00mm
C8: 1nF; C_Disc_D8.0mm_W5.0mm_P7.50mm
C9: 10nF; C_Disc_D8.0mm_W5.0mm_P7.50mm
D1, D2: 1N4007; D_DO-41_SOD81_P10.16mm_Horizontal
J1: SIN-TRI-SQU-PWM; PinHeader_1x03_P2.54mm_Vertical
J2: BTN Range; PinHeader_1x02_P2.54mm_Vertical
J3: BTN Form; PinHeader_1x02_P2.54mm_Vertical
J4: BTN PWM; PinHeader_1x02_P2.54mm_Vertical
J5: FreqRange; PinHeader_1x02_P2.54mm_Vertical
J6: WaveA1; PinHeader_1x01_P2.54mm_Vertical
J7: FreqCount; PinHeader_1x01_P2.54mm_Vertical
J8: Display; PinHeader_1x04_P2.54mm_Vertical
J9: 14V; TerminalBlock_Altech_AK300-2_P5.00mm
J10: 12V GND 5V; PinHeader_1x03_P2.54mm_Vertical
J11: WaveA2; PinHeader_1x01_P2.54mm_Vertical
J12: MO; PinHeader_1x01_P2.54mm_Vertical
K1: G6S-2; Relay_DPDT_Omron_G6S-2
Q1: BC337; TO-220-3_Vertical
R1, R2, R9, R10: 390R; R_Axial_DIN0207_L6.3mm_D2.5mm_P10.16mm_Horizontal
R3, R5: 390; R_Axial_DIN0207_L6.3mm_D2.5mm_P10.16mm_Horizontal
R4: 270; R_Axial_DIN0207_L6.3mm_D2.5mm_P10.16mm_Horizontal
R6, R7, R8: 10k; R_Axial_DIN0207_L6.3mm_D2.5mm_P10.16mm_Horizontal
RV1: 500; Potentiometer_Bourns_3266Y_Vertical
RV2, RV3: 50k; Potentiometer_Bourns_3266Y_Vertical
U1: LTV-847; DIP-16_W7.62mm
U2: LM7812_TO220; TO-220-3_Vertical
U3: LM7805_TO220; TO-220-3_Vertical

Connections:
GND: A1.4, A1.29, C3.2, C4.2, C5.2, C6.2, C7.2, J2.2, J3.2, J4.2, J8.4, J9.2, J10.2, Q1.3, R8.2, U1.2, U1.4, U1.6, U1.8, U2.2, U3.2
unnamed: A1.1, R10.2
unnamed: A1.5, R9.2
unnamed: A1.6, R2.2
unnamed: A1.7, R1.2
unnamed: A1.8, J7.1
unnamed: A1.9, R3.1
unnamed: A1.10, R4.1
unnamed: A1.11, R5.1
unnamed: A1.12, R6.1
unnamed: A1.13, J2.1
unnamed: A1.14, J3.1
unnamed: A1.15, J4.1
unnamed: A1.23, J8.2
unnamed: A1.24, J8.1
unnamed: A1.27, C6.1, D2.1, J8.3, J10.3, K1.1, U3.3
unnamed: C1.1, C2.2, C8.1, C9.1, J5.1
unnamed: C1.2, U1.12
unnamed: C2.1, U1.10
unnamed: C3.1, D1.1, U2.1
unnamed: C4.1, C5.1, J10.1, R7.1, U2.3, U3.1
unnamed: C7.1, K1.9, R7.2, R8.1
unnamed: C8.2, U1.16
unnamed: C9.2, U1.14
unnamed: D1.2, J9.1
unnamed: D2.2, K1.12, Q1.1
unnamed: J1.1, R3.2
unnamed: J1.2, R4.2
unnamed: J1.3, R5.2
unnamed: J5.2, U1.9, U1.11, U1.13, U1.15
unnamed: J6.1, RV1.1, RV1.2
unnamed: J11.1, K1.5
unnamed: J12.1, RV2.2, RV2.3, RV3.2, RV3.3
unnamed: K1.4, RV1.3
unnamed: K1.8, RV2.1
unnamed: K1.10, RV3.1
unnamed: Q1.2, R6.2
unnamed: R1.1, U1.1
unnamed: R2.1, U1.3
unnamed: R9.1, U1.5
unnamed: R10.1, U1.7

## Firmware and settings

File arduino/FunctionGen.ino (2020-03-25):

//SCULLCOM HOBBY ELECTRONICS
//FUNCTION GENERATOR
//Software Version 2
#include <Wire.h> 
#include <LiquidCrystal_I2C.h>
#include <FreqCounter.h>    //Frequency Counter Library

/*
 * D3 low medium range
 * D4 low frequence range
 * D5 is input for frequency
 * D6 SIN/SQU/TRI/PWM Pin 1 SQU ON=1
 * D7 SIN/SQU/TRI/PWM Pin 2 PWM ON=1
 * D8 SIN/SQU/TRI/PWM Pin 3 SIN/TRI ON ON=SIN ON
 * D9 Relay on/off ON=TRI OFF=SIN
 * D10 Range switch button
 * D11 Form switch button
 * D12 PWM on/off button
 * A4 Display I2C SDA
 * A5 Display I2C SCL

*/

LiquidCrystal_I2C lc(0x27,20,4);

unsigned long frq=0;
volatile bool frqrangetriggerInUse=false;
volatile bool waveformtriggerInUse=false;
volatile bool pwmtriggerInUse=false;

volatile int frqrange=-1;
volatile int waveform=-1;
volatile bool startup=true;
volatile bool dot=false;

volatile bool pwmenabled=false;

int lowrangepin=1;
int belowmediumrangepin=2;
int mediumrangepin=3;
int abovemediumrangepin=4;


int rangebuttonpin=10;

int waveformbuttonpin = 11;
int pwmbuttonpin = 12;

int squareswitch = 6;
int pwmswitch = 7;
int sintrivssquswitch = 8;
int sinvstriswitch = 9;

volatile bool pwmchanged=false;

void setup()
{
  lc.init();
  // Print a message to the LCD.
  lc.backlight();
  lc.setCursor(0,0);
  lc.print("Function Gen");
  lc.setCursor(0,1);
  lc.print("HW: 1.0  SW: 1.0");

  pinMode(lowrangepin, OUTPUT); //
  pinMode(belowmediumrangepin, OUTPUT); //
  pinMode(mediumrangepin, OUTPUT); //
  pinMode(abovemediumrangepin, OUTPUT); //
    
  pinMode(rangebuttonpin, INPUT_PULLUP);
  pinMode(waveformbuttonpin, INPUT_PULLUP);
  pinMode(pwmbuttonpin, INPUT_PULLUP);

  pinMode(squareswitch, OUTPUT);
  pinMode(pwmswitch, OUTPUT);
  pinMode(sintrivssquswitch, OUTPUT);
  pinMode(sinvstriswitch, OUTPUT);

  
  lc.setCursor(0,0);
  delay(2000);
  lc.print("                ");
  lc.setCursor(0,1);
  lc.print("                ");

  //init
  frqrange=1; //start medium, so medium-1
  waveform=0; //Start triangle, to unload the relay at start
  pwmenabled=false; //PWM off
}

void printNumber(unsigned long v) {
    unsigned long ones;
    unsigned long tens;
    unsigned long hundreds;
    unsigned long thousands;
    unsigned long tenthousands;
    unsigned long hundredthousands;

    ones=v%10;
    v=v/10;
    tens=v%10;
    v=v/10;
    hundreds=v%10;
    v=v/10;
    thousands=v%10;
    v=v/10;
    tenthousands=v%10;
    v=v/10;
    hundredthousands=v;

    lc.setCursor(0,0);
    lc.print("Hz       ");
    lc.setCursor(3,0);
    lc.print(frq);
    

    if(frq<100000)
    {
    //lc.setRow(0,7,B00000000);
    }
    else
    {
      //lc.setDigit(0,7,(byte)hundredthousands,false);
    }
    
    
    if(frq<10000)
    {
    //lc.setRow(0,6,B00000000);
    }
    else
    {
      //lc.setDigit(0,6,(byte)tenthousands,false);
    }

    
    if(frq<1000)
    {
    //lc.setRow(0,5,B00000000);
    }
    else
    {
      //lc.setDigit(0,5,(byte)thousands,false);
    }   

 if(frq<100)
    {
    //lc.setRow(0,4,B00000000);
    }
    else
    {
      //lc.setDigit(0,4,(byte)hundreds,false);
    }

if(frq<10)
    {
    //lc.setRow(0,3,B00000000);
    }
    else
    {
      //lc.setDigit(0,3,(byte)tens,false);
    }
    
    //lc.setDigit(0,2,(byte)ones,false);
    
    //lc.setRow(0,0,B00110111); //print letter H for Hertz
}

void loop() { 

  if(digitalRead(rangebuttonpin) == LOW or startup==true) {
    if(frqrangetriggerInUse==false) {  
      frqrange++;
      if (frqrange>4) {
        frqrange=0;  
      }
      frqrangetriggerInUse=true;
      lc.setCursor(0,1);
      lc.print("                ");

      if(frqrange==0) {
        digitalWrite(lowrangepin, HIGH);
        digitalWrite(belowmediumrangepin, LOW);
        digitalWrite(mediumrangepin, LOW);
        digitalWrite(abovemediumrangepin, LOW);
        lc.setCursor(0,1);
        lc.print("Range: 1-10");
      }
      if(frqrange==1) {
        digitalWrite(lowrangepin, LOW);
        digitalWrite(belowmediumrangepin, HIGH);
        digitalWrite(mediumrangepin, LOW);
        digitalWrite(abovemediumrangepin, LOW);
        lc.setCursor(0,1);
        lc.print("Range: 10-100");
      }
      if(frqrange==2) {
        digitalWrite(lowrangepin, LOW);
        digitalWrite(belowmediumrangepin, LOW);
        digitalWrite(mediumrangepin, HIGH);
        digitalWrite(abovemediumrangepin, LOW);
        lc.setCursor(0,1);
        lc.print("Range: 100-1k");
      }
      if(frqrange==3) {
        digitalWrite(lowrangepin, LOW);
        digitalWrite(belowmediumrangepin, LOW);
        digitalWrite(mediumrangepin, LOW);
        digitalWrite(abovemediumrangepin, HIGH);
        lc.setCursor(0,1);
        lc.print("Range: 1-10k");
      }
      if(frqrange==4) {
        digitalWrite(lowrangepin, LOW);
        digitalWrite(belowmediumrangepin, LOW);
        digitalWrite(mediumrangepin, LOW);
        digitalWrite(abovemediumrangepin, LOW);
        lc.setCursor(0,1);
        lc.print("Range: 10-100k");
      }
      
    }
      
  } else {
    if(frqrangetriggerInUse==true) {
      frqrangetriggerInUse=false;
    }
  }

  if(digitalRead(pwmbuttonpin) == LOW) {
    if(pwmtriggerInUse==false) {  
      if(pwmenabled==false) {
        pwmenabled=true;
        waveform=waveform+3;
      } else {
        pwmenabled=false;
        waveform=waveform-3;
      }
      //lc.setCursor(15,0);
      //lc.print("x");
      pwmtriggerInUse=true;
      pwmchanged=true;
      
    }
      
  } else {
    if(pwmtriggerInUse==true) {
      pwmtriggerInUse=false;
    }
  }


  if(digitalRead(waveformbuttonpin) == LOW or startup==true or pwmchanged==true) {
    
    if(waveformtriggerInUse==false) {  
      if(pwmchanged==false) {
        waveform++;
      }
      
      if(pwmenabled==true) {
        if(waveform>5){
          waveform=3; 
        }
      } else {
        if(waveform>2){
          waveform=0; 
        } 
      }
         
      waveformtriggerInUse=true;
      lc.setCursor(10,0);
      lc.print("------");
      
      //lc.setCursor(15,0);
      //lc.print(waveform);

      
      
      if(waveform==0) {
        digitalWrite(squareswitch, LOW);
        digitalWrite(pwmswitch, LOW);
        digitalWrite(sintrivssquswitch, HIGH);
        digitalWrite(sinvstriswitch, HIGH);
        lc.setCursor(10,0);
        lc.print("   SIN");
      }
      if(waveform==1) {
        digitalWrite(squareswitch, LOW);
        digitalWrite(pwmswitch, LOW);
        digitalWrite(sintrivssquswitch, HIGH);
        digitalWrite(sinvstriswitch, LOW);
        lc.setCursor(10,0);
        lc.print("   TRI");
      }
      if(waveform==2) {
        digitalWrite(squareswitch, HIGH);
        digitalWrite(pwmswitch, LOW);
        digitalWrite(sintrivssquswitch, LOW);
        digitalWrite(sinvstriswitch, LOW);
        lc.setCursor(10,0);
        lc.print("   SQU");
      }
      
      if(waveform==3) {
        digitalWrite(squareswitch, LOW);
        digitalWrite(pwmswitch, HIGH);
        digitalWrite(sintrivssquswitch, HIGH);
        digitalWrite(sinvstriswitch, HIGH);
        lc.setCursor(10,0);
        lc.print("SINRMP");
      }
      if(waveform==4) {
        digitalWrite(squareswitch, LOW);
        digitalWrite(pwmswitch, HIGH);
        digitalWrite(sintrivssquswitch, HIGH);
        digitalWrite(sinvstriswitch, LOW);
        lc.setCursor(10,0);
        lc.print("TRIRMP");
      }
      if(waveform==5) {
        digitalWrite(squareswitch, HIGH);
        digitalWrite(pwmswitch, HIGH);
        digitalWrite(sintrivssquswitch, LOW);
        digitalWrite(sinvstriswitch, LOW);
        lc.setCursor(10,0);
        lc.print("   PWM");
      }
      
    }
      
  } else {
    if(waveformtriggerInUse==true) {
      waveformtriggerInUse=false;
    }
  }

  pwmchanged=false;
 
  //#######################################################
  startup=false;
  
  // wait if any serial is going on
  FreqCounter::f_comp=140;      // Calibation Value of 140 - change value to calibrate with professional Frequency Counter if one available.
  FreqCounter::start(1000);     // 1000 mSec Gate Time

  while (FreqCounter::f_ready == 0) 
  frq=FreqCounter::f_freq;
  printNumber(frq);

  if(dot==false) {
    dot=true;  
    lc.setCursor(15,1);
    lc.print(".");
  } else {
    dot=false;
    lc.setCursor(15,1);
    lc.print(" ");
  }
  
  delay(20);
}

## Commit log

2020-03-26 more media and a changed part of the enclosure
    [Oben.stl]
2023-01-09 circuit kicad updates
    updated circuits to last kicad version
    [FunctiongeneratorMK3Frequency.kicad_pcb, FunctiongeneratorMK3PowerControl.kicad_pcb]
